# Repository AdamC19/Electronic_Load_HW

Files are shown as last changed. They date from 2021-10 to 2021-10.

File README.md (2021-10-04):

# Electronic_Load_HW
Hardware source files for my multi-channel electronic load. Read more about this device [here](http://www.acordingley.us/electronic-load/).
## Electronic_Load_Controller/
Files for the controller, of which there should be 1 per electronic load.
## Electronic_Load_Module/
Files for the modules/channels. I designed it to have 8 of these per electronic load.

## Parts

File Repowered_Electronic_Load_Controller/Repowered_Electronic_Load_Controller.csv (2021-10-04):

Reference | Quantity | Value | Footprint | Datasheet
C10 C8 C11 | 3 | 0.01u | Capacitor_SMD:C_0603_1608Metric | ~
C2 C1 C6 C7 C9 C3 | 6 | 0.1u | Capacitor_SMD:C_0603_1608Metric | ~
C5 C4 | 2 | 4.7u | Capacitor_SMD:C_0805_2012Metric | ~
D1 D2 | 2 | MBR0540 | Diode_SMD:D_SOD-123 | ~
D3 | 1 | IN-S63BT5B | LED_SMD:LED_0603_1608Metric | ~
H1 H2 H3 H4 H5 | 5 | MountingHole_Pad | MountingHole:MountingHole_2.5mm_Pad | ~
J1 | 1 | Conn_01x02_Male | Connector_Phoenix_MC:PhoenixContact_MC_1,5_2-G-3.5_1x02_P3.50mm_Horizontal | ~
J2 J5 J8 J9 J10 J11 J13 J12 | 8 | 1844249 | Connector_Phoenix_MC:PhoenixContact_MC_1,5_5-G-3.5_1x05_P3.50mm_Horizontal | ~
J3 J4 | 2 | Conn_01x04_Male | Connector_PinHeader_2.54mm:PinHeader_1x04_P2.54mm_Vertical | ~
J6 | 1 | USB_B_Micro | Connector_USB:USB_Micro-B_Molex-105017-0001 | ~
J7 | 1 | 1844210 | Connector_Phoenix_MC:PhoenixContact_MC_1,5_2-G-3.5_1x02_P3.50mm_Horizontal | ~
R2 R1 R5 | 3 | 1.5k | Resistor_SMD:R_0805_2012Metric | ~
R3 | 1 | 100k | Resistor_SMD:R_0805_2012Metric | ~
R4 | 1 | 6.8k | Resistor_SMD:R_0805_2012Metric | ~
R6 R7 | 2 | 4.7k | Resistor_SMD:R_0805_2012Metric | ~
R8 | 1 | 100 | Resistor_SMD:R_0805_2012Metric | ~
U1 | 1 | LP2985-3.3 | Package_TO_SOT_SMD:SOT-23-5 | http://www.ti.com/lit/ds/symlink/lp2985.pdf
U2 U4 U5 | 3 | 74HC4051 | Package_SO:SOIC-16_3.9x9.9mm_P1.27mm | http://www.ti.com/lit/ds/symlink/cd74hc4051.pdf
U3 | 1 | STM32L432KCUx | Package_DFN_QFN:QFN-32-1EP_5x5mm_P0.5mm_EP3.45x3.45mm | http://www.st.com/st-web-ui/static/active/en/resource/technical/document/datasheet/DM00257205.pdf

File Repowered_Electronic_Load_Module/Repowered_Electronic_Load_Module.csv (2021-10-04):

Reference | Quantity | Value | Footprint | Datasheet
C2 C1 C8 C3 | 4 | 0.1u | Capacitor_SMD:C_0603_1608Metric | ~
C4 C7 | 2 | 4.7u | Capacitor_SMD:C_0805_2012Metric | ~
C5 C6 | 2 | 4700p | Capacitor_SMD:C_0603_1608Metric | ~
FB1 | 1 | 120@100MHz | Inductor_SMD:L_0805_2012Metric | ~
J1 J3 | 2 | Screw_Terminal_01x01 | MountingHole:MountingHole_4.3mm_M4_Pad_Via | ~
J2 | 1 | Conn_01x05_Male | Connector_Phoenix_MC:PhoenixContact_MC_1,5_5-G-3.5_1x05_P3.50mm_Horizontal | ~
NT1 | 1 | Net-Tie_2 | NetTie:NetTie-2_SMD_Pad0.5mm | ~
Q1 | 1 | IRFP27N60KPBF | Package_TO_SOT_THT:TO-247-3_Vertical | ~
R2 R1 | 2 | 2.2k | Resistor_SMD:R_0805_2012Metric | ~
R4 R3 R8 R5 | 4 | 1k | Resistor_SMD:R_0805_2012Metric | ~
R6 R9 | 2 | 0.01 | Resistor_SMD:R_2512_6332Metric | ~
R7 | 1 | 33k | Resistor_SMD:R_0805_2012Metric | ~
U1 | 1 | DAC101C081CIMK | Package_TO_SOT_SMD:SOT-23-6 | http://www.ti.com/lit/ds/symlink/dac101c081.pdf
U2 | 1 | TLV9151IDBVR | Package_TO_SOT_SMD:SOT-23-5 | http://www.ti.com/lit/ds/symlink/tlv2375.pdf
U3 | 1 | OPA330xxDBV | Package_TO_SOT_SMD:SOT-23-5 | http://www.ti.com/lit/ds/symlink/opa330.pdf
U4 | 1 | LP2985-3.3 | Package_TO_SOT_SMD:SOT-23-5 | http://www.ti.com/lit/ds/symlink/lp2985.pdf

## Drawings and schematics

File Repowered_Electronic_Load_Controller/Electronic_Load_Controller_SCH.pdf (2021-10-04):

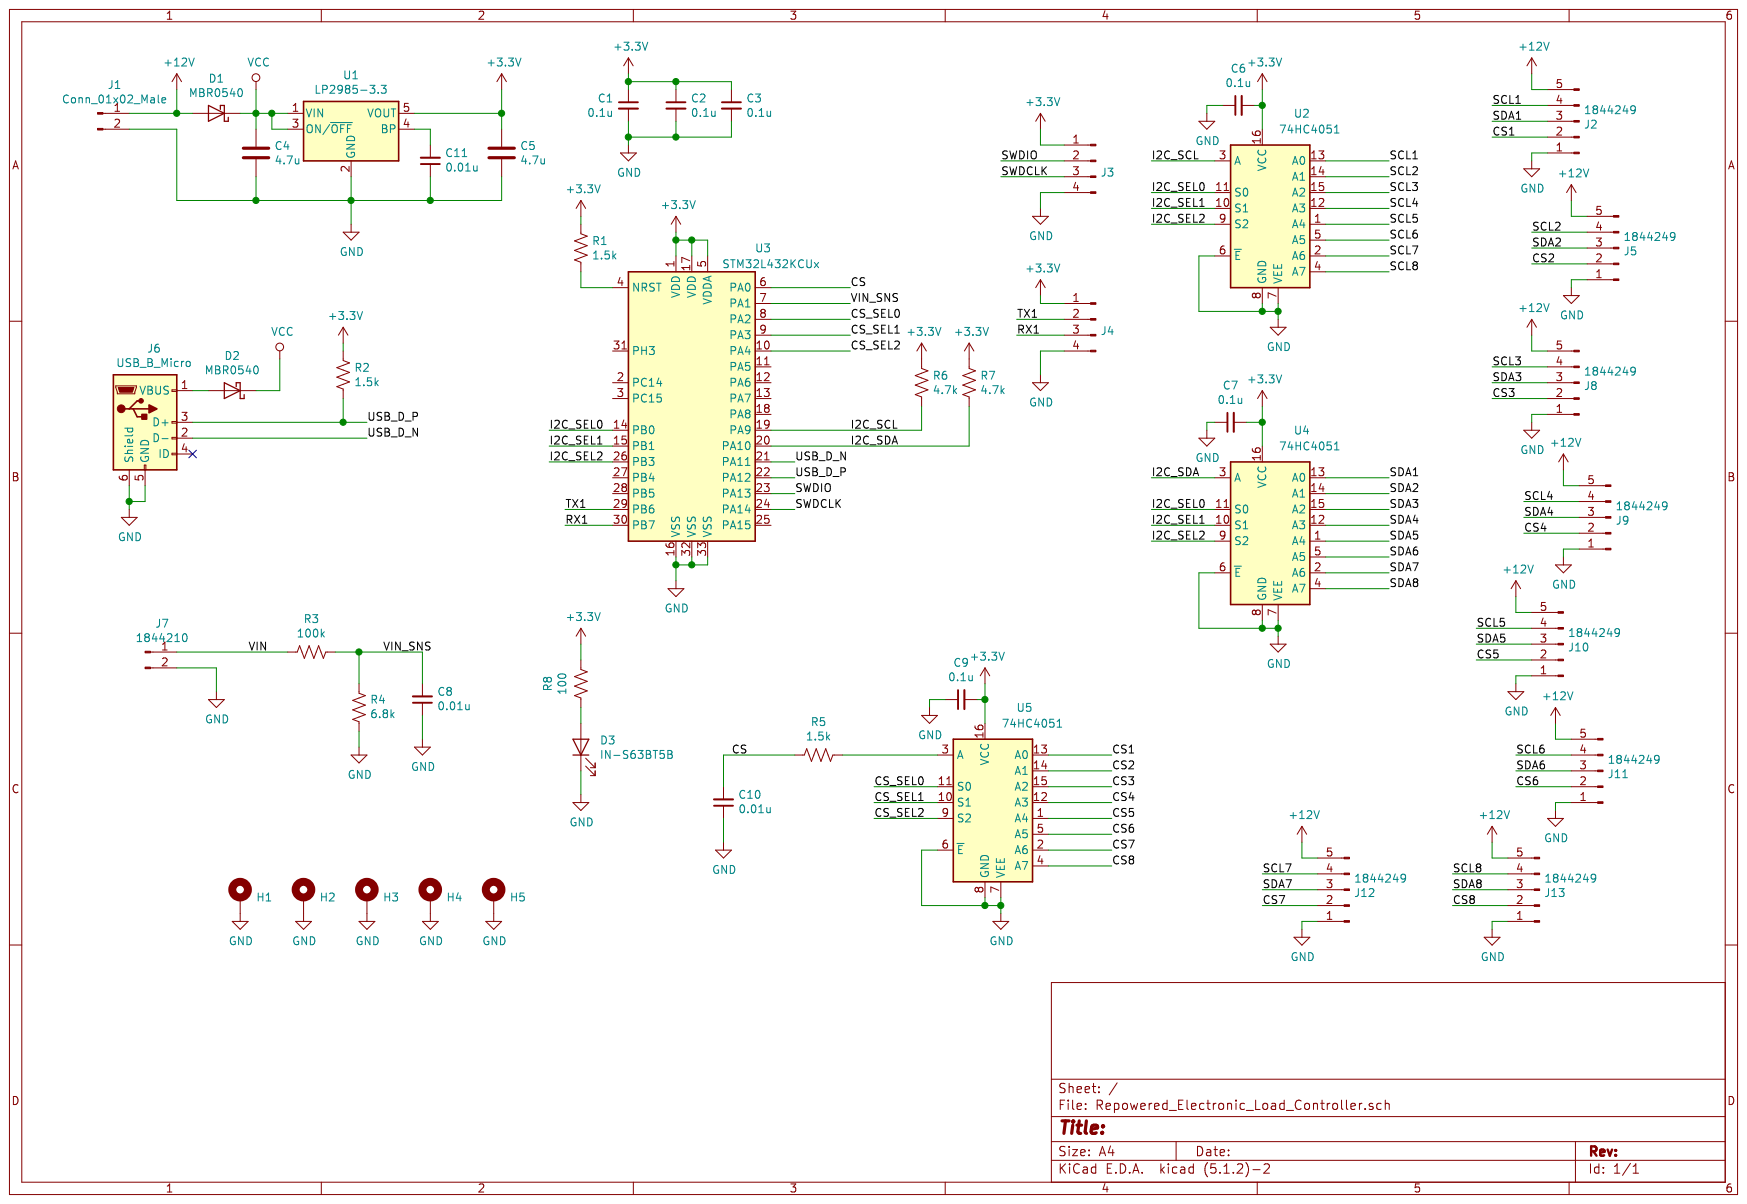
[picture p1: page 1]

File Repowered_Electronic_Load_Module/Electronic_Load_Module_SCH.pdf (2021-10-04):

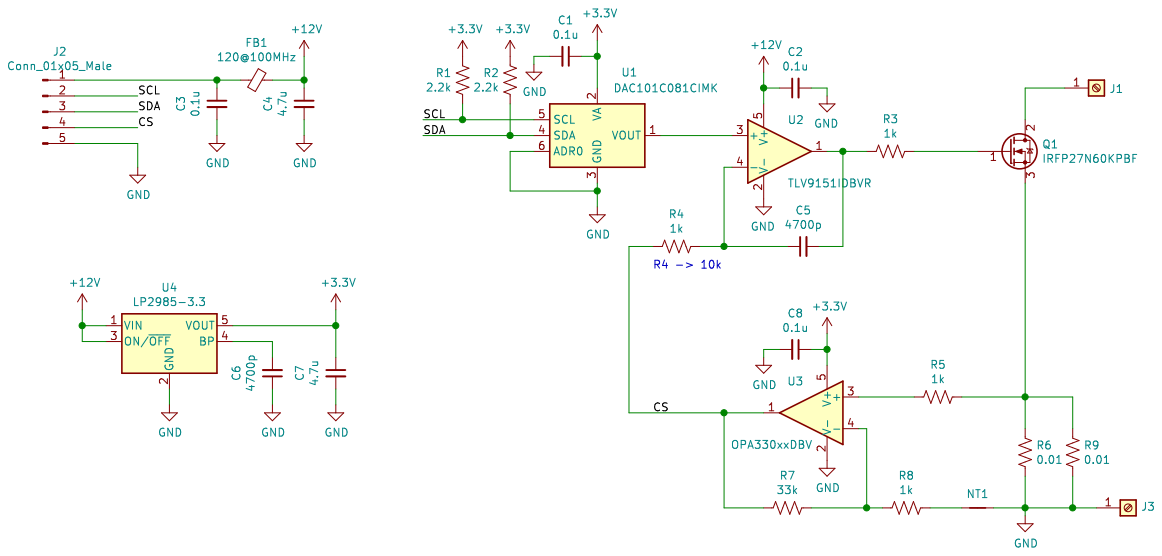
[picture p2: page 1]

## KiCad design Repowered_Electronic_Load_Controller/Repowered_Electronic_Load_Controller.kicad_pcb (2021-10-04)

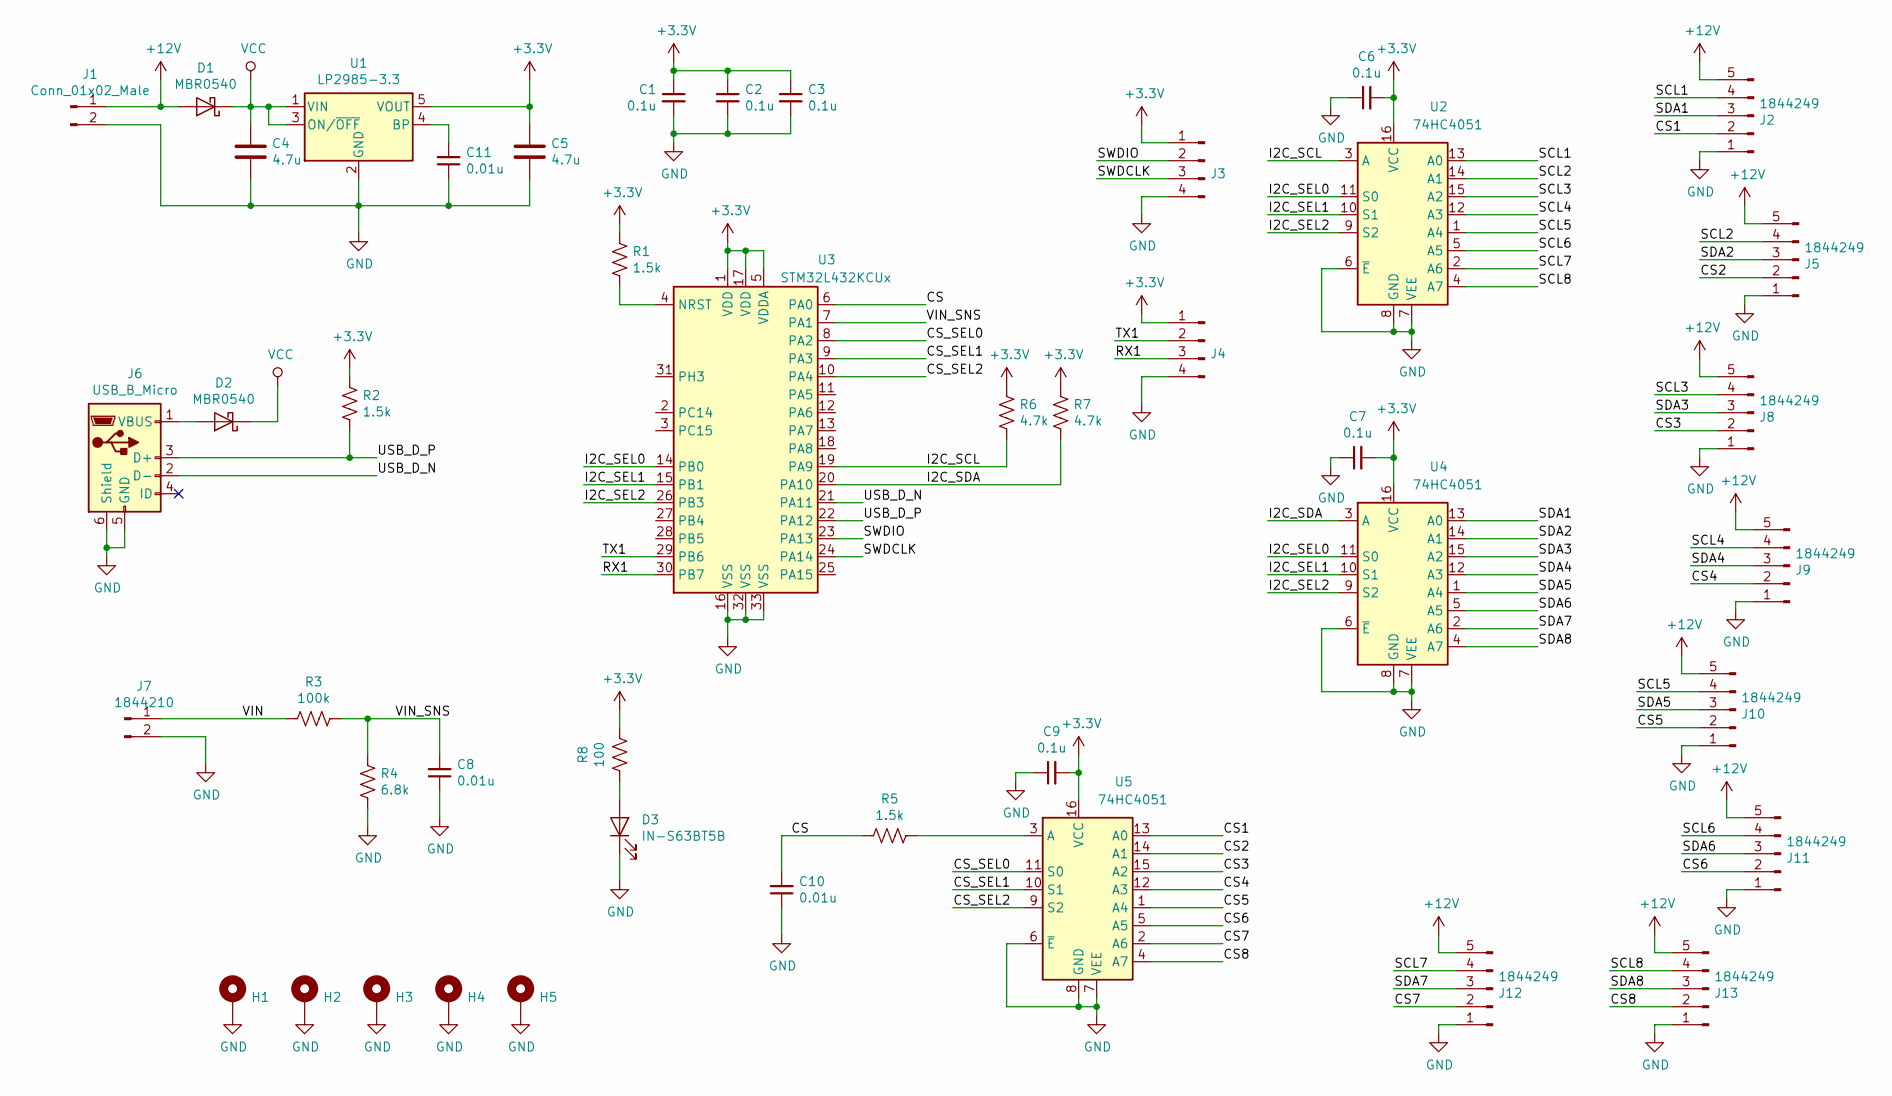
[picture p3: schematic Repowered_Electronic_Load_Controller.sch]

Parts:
C1, C2, C3, C6, C7, C9: 0.1u; C_0603_1608Metric
C4, C5: 4.7u; C_0805_2012Metric
C8, C10, C11: 0.01u; C_0603_1608Metric
D1, D2: MBR0540; D_SOD-123
D3: IN-S63BT5B; LED_0603_1608Metric
H1, H2, H3, H4, H5: MountingHole_Pad; MountingHole_2.5mm_Pad
J1: Conn_01x02_Male; PhoenixContact_MC_1,5_2-G-3.5_1x02_P3.50mm_Horizontal
J2, J5, J8, J9, J10, J11, J12, J13: 1844249; PhoenixContact_MC_1,5_5-G-3.5_1x05_P3.50mm_Horizontal
J3, J4: Conn_01x04_Male; PinHeader_1x04_P2.54mm_Vertical
J6: USB_B_Micro; USB_Micro-B_Molex-105017-0001
J7: 1844210; PhoenixContact_MC_1,5_2-G-3.5_1x02_P3.50mm_Horizontal
R1, R2, R5: 1.5k; R_0805_2012Metric
R3: 100k; R_0805_2012Metric
R4: 6.8k; R_0805_2012Metric
R6, R7: 4.7k; R_0805_2012Metric
R8: 100; R_0805_2012Metric
U1: LP2985-3.3; SOT-23-5
U2, U4, U5: 74HC4051; SOIC-16_3.9x9.9mm_P1.27mm
U3: STM32L432KCUx; QFN-32-1EP_5x5mm_P0.5mm_EP3.45x3.45mm

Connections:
+3V3: C1.1, C2.1, C3.1, C5.1, C6.2, C7.2, C9.2, J3.1, J4.1, R1.1, R2.1, R6.1, R7.1, R8.2, U1.5 (VOUT), U2.16 (VCC), U3.1 (VDD), U3.5 (VDDA), U3.17 (VDD), U4.16 (VCC), U5.16 (VCC)
+12V: D1.2 (A), J1.1, J2.5, J5.5, J8.5, J9.5, J10.5, J11.5, J12.5, J13.5
/CS: C10.2, R5.1, U3.6 (PA0)
/CS1: J2.2, U5.13 (A0)
/CS2: J5.2, U5.14 (A1)
/CS3: J8.2, U5.15 (A2)
/CS4: J9.2, U5.12 (A3)
/CS5: J10.2, U5.1 (A4)
/CS6: J11.2, U5.5 (A5)
/CS7: J12.2, U5.2 (A6)
/CS8: J13.2, U5.4 (A7)
/CS_SEL0: U3.8 (PA2), U5.11 (S0)
/CS_SEL1: U3.9 (PA3), U5.10 (S1)
/CS_SEL2: U3.10 (PA4), U5.9 (S2)
/I2C_SCL: R6.2, U2.3 (A), U3.19 (PA9)
/I2C_SDA: R7.2, U3.20 (PA10), U4.3 (A)
/I2C_SEL0: U2.11 (S0), U3.14 (PB0), U4.11 (S0)
/I2C_SEL1: U2.10 (S1), U3.15 (PB1), U4.10 (S1)
/I2C_SEL2: U2.9 (S2), U3.26 (PB3), U4.9 (S2)
/RX1: J4.3, U3.30 (PB7)
/SCL1: J2.4, U2.13 (A0)
/SCL2: J5.4, U2.14 (A1)
/SCL3: J8.4, U2.15 (A2)
/SCL4: J9.4, U2.12 (A3)
/SCL5: J10.4, U2.1 (A4)
/SCL6: J11.4, U2.5 (A5)
/SCL7: J12.4, U2.2 (A6)
/SCL8: J13.4, U2.4 (A7)
/SDA1: J2.3, U4.13 (A0)
/SDA2: J5.3, U4.14 (A1)
/SDA3: J8.3, U4.15 (A2)
/SDA4: J9.3, U4.12 (A3)
/SDA5: J10.3, U4.1 (A4)
/SDA6: J11.3, U4.5 (A5)
/SDA7: J12.3, U4.2 (A6)
/SDA8: J13.3, U4.4 (A7)
/SWDCLK: J3.3, U3.24 (PA14)
/SWDIO: J3.2, U3.23 (PA13)
/TX1: J4.2, U3.29 (PB6)
/USB_D_N: J6.2 (D-), U3.21 (PA11)
/USB_D_P: J6.3 (D+), R2.2, U3.22 (PA12)
/VIN: J7.1, R3.1
/VIN_SNS: C8.2, R3.2, R4.2, U3.7 (PA1)
GND: C1.2, C2.2, C3.2, C4.2, C5.2, C6.1, C7.1, C8.1, C9.1, C10.1, C11.1, D3.1 (K), H1.1, H2.1, H3.1, H4.1, H5.1, J1.2, J2.1, J3.4, J4.4, J5.1, J6.5 (GND), J6.6 (Shield), J7.2, J8.1, J9.1, J10.1, J11.1, J12.1, J13.1, R4.1, U1.2 (GND), U2.6 (~E), U2.7 (VEE), U2.8 (GND), U3.16 (VSS), U3.32 (VSS), U3.33 (VSS), U4.6 (~E), U4.7 (VEE), U4.8 (GND), U5.6 (~E), U5.7 (VEE), U5.8 (GND)
unnamed: C11.2, U1.4 (BP)
unnamed: D2.2 (A), J6.1 (VBUS)
unnamed: D3.2 (A), R8.1
unnamed: R1.2, U3.4 (NRST)
unnamed: R5.2, U5.3 (A)
VCC: C4.1, D1.1 (K), D2.1 (K), U1.1 (VIN), U1.3 (ON/~OFF~)

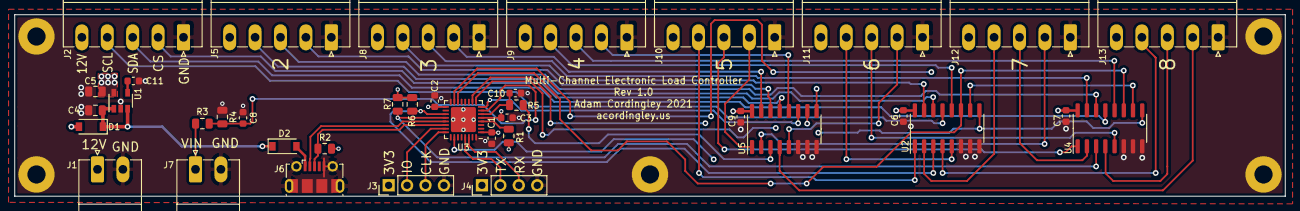
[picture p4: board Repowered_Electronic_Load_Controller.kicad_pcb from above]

Board: 4 copper layers, 175.0 x 25.0 mm, 43 parts (0 on the bottom side), 49 nets.

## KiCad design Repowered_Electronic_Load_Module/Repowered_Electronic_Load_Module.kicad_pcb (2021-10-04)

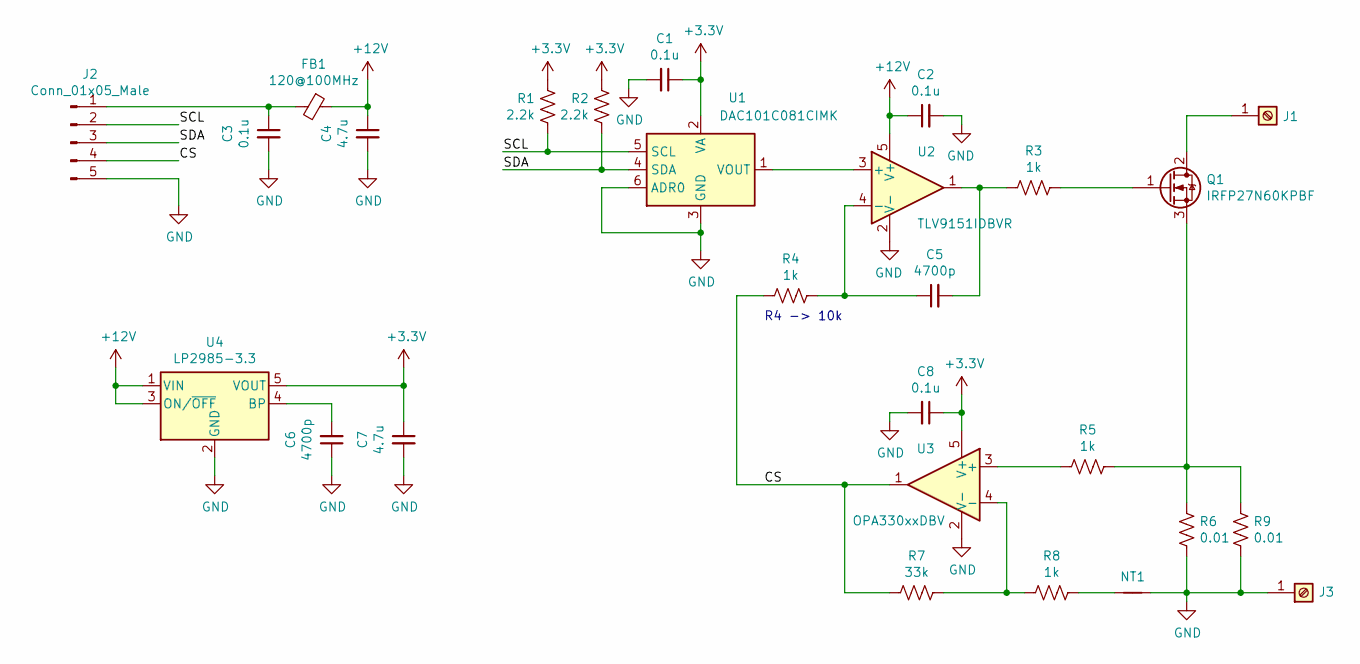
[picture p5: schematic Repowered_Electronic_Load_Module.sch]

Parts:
C1, C2, C3, C8: 0.1u; C_0603_1608Metric
C4, C7: 4.7u; C_0805_2012Metric
C5, C6: 4700p; C_0603_1608Metric
FB1: 120@100MHz; L_0805_2012Metric
J1, J3: Screw_Terminal_01x01; MountingHole_4.3mm_M4_Pad_Via
J2: Conn_01x05_Male; PhoenixContact_MC_1,5_5-G-3.5_1x05_P3.50mm_Horizontal
NT1: Net-Tie_2; NetTie-2_SMD_Pad0.5mm
Q1: IRFP27N60KPBF; TO-247-3_Vertical
R1, R2: 2.2k; R_0805_2012Metric
R3, R4, R5, R8: 1k; R_0805_2012Metric
R6, R9: 0.01; R_2512_6332Metric
R7: 33k; R_0805_2012Metric
U1: DAC101C081CIMK; SOT-23-6
U2: TLV9151IDBVR; SOT-23-5
U3: OPA330xxDBV; SOT-23-5
U4: LP2985-3.3; SOT-23-5

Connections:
+3V3: C1.1, C7.1, C8.1, R1.1, R2.1, U1.2 (VA), U3.5 (V+), U4.5 (VOUT)
+12V: C2.1, C4.1, FB1.1, U2.5 (V+), U4.1 (VIN), U4.3 (ON/~OFF~)
/CS: J2.4, R4.2, R7.2, U3.1
/SCL: J2.2, R1.2, U1.5 (SCL)
/SDA: J2.3, R2.2, U1.4 (SDA)
GND: C1.2, C2.2, C3.2, C4.2, C6.1, C7.2, C8.2, J2.5, J3.1, NT1.2, R6.2, R9.2, U1.3 (GND), U1.6 (ADR0), U2.2 (V-), U3.2 (V-), U4.2 (GND)
unnamed: C3.1, FB1.2, J2.1
unnamed: C5.1, R4.1, U2.4 (-)
unnamed: C5.2, R3.2, U2.1
unnamed: C6.2, U4.4 (BP)
unnamed: J1.1, Q1.2 (D)
unnamed: NT1.1, R8.1
unnamed: Q1.1 (G), R3.1
unnamed: Q1.3 (S), R5.1, R6.1, R9.1
unnamed: R5.2, U3.3 (+)
unnamed: R7.1, R8.2, U3.4 (-)
unnamed: U1.1 (VOUT), U2.3 (+)

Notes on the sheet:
R4 -> 10k

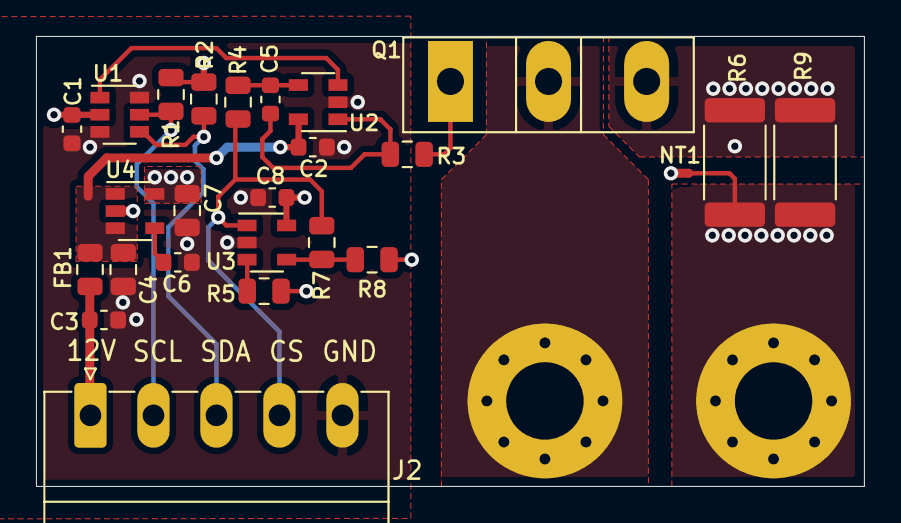
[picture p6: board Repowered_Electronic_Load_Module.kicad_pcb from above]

Board: 4 copper layers, 46.0 x 25.0 mm, 27 parts (0 on the bottom side), 17 nets.
